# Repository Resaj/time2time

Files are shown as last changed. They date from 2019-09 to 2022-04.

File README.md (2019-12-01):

# time2time

Chronometer with partials measurement for the line-following competitions.

Characteristics:
- ESP32 module (STM microcontroller + Bluetooth + Wifi)
- Industrial distance sensor for robots pass-through detection
- Lipo 1S battery
- USB Lipo battery charge management
- I2C OLED display port
- Buzzer for robots pass-through signaling
- RGB led for chronometer status signaling
- Firmware upload via USB
- Address selection to synchronize several modules
- Expansion port for future improvements

<p align="center">
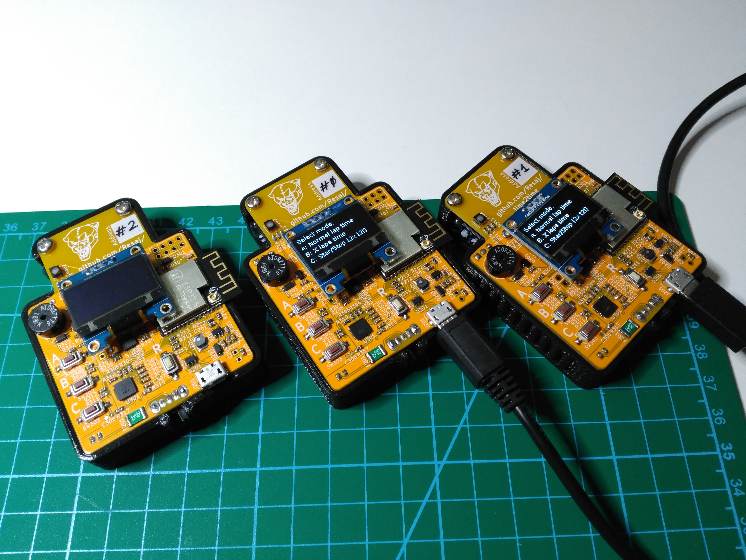
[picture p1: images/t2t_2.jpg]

</p>

This project has been motivated because of the limitations that the last chronometer had. The main purpose is to communicate the system with the PC of the competition organization and facilitate the taking and visualization of the times.

## Author

[Rubén Espino San José](https://github.com/Resaj)

## License

<p align="center">

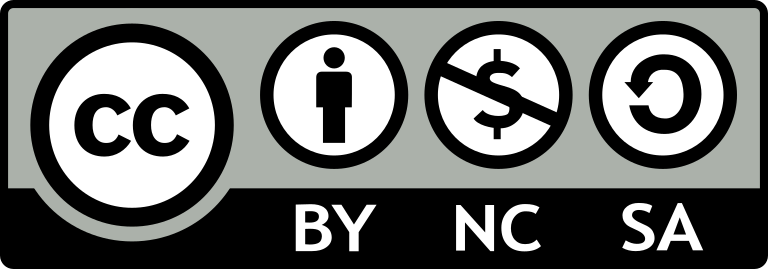
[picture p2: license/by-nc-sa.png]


</p>

_All these products are released under [Creative Commons Attribution-NonCommercial-ShareAlike 4.0 International License](http://creativecommons.org/licenses/by-nc-sa/4.0/)._

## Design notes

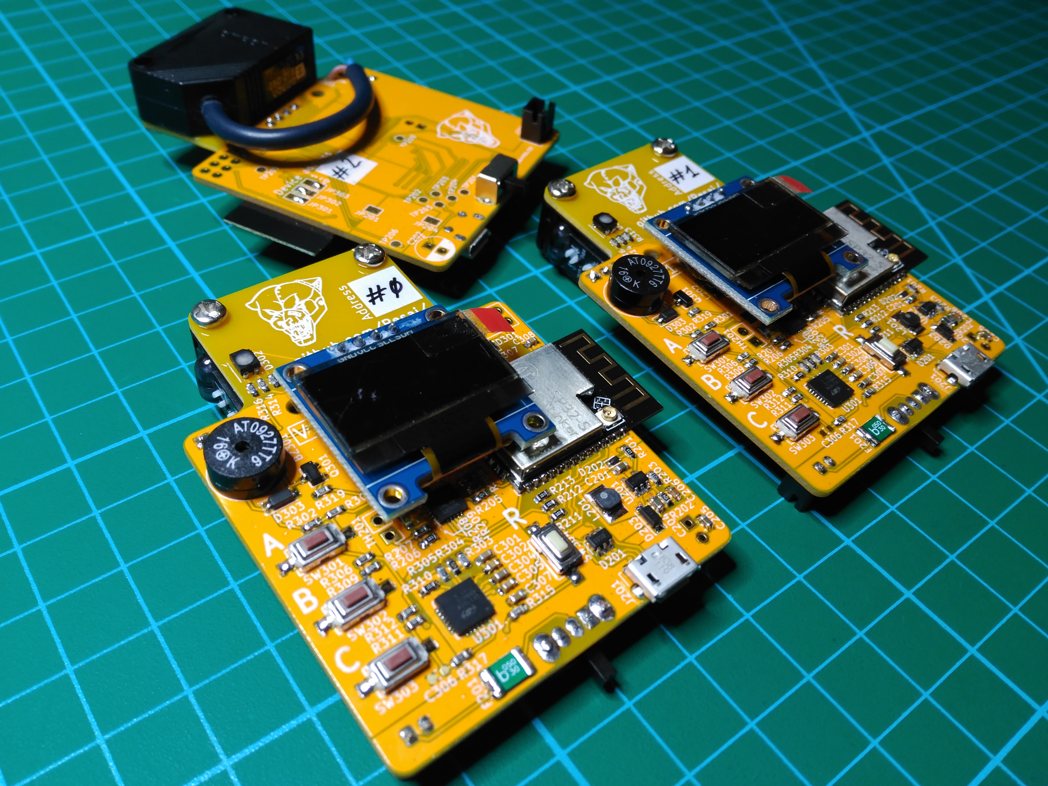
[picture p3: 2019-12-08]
images/t2t_3.jpg

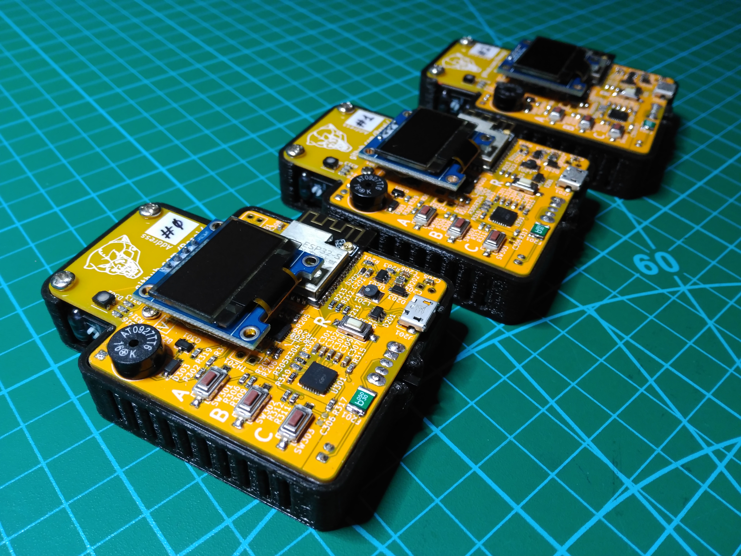
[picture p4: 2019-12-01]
images/t2t_1.jpg

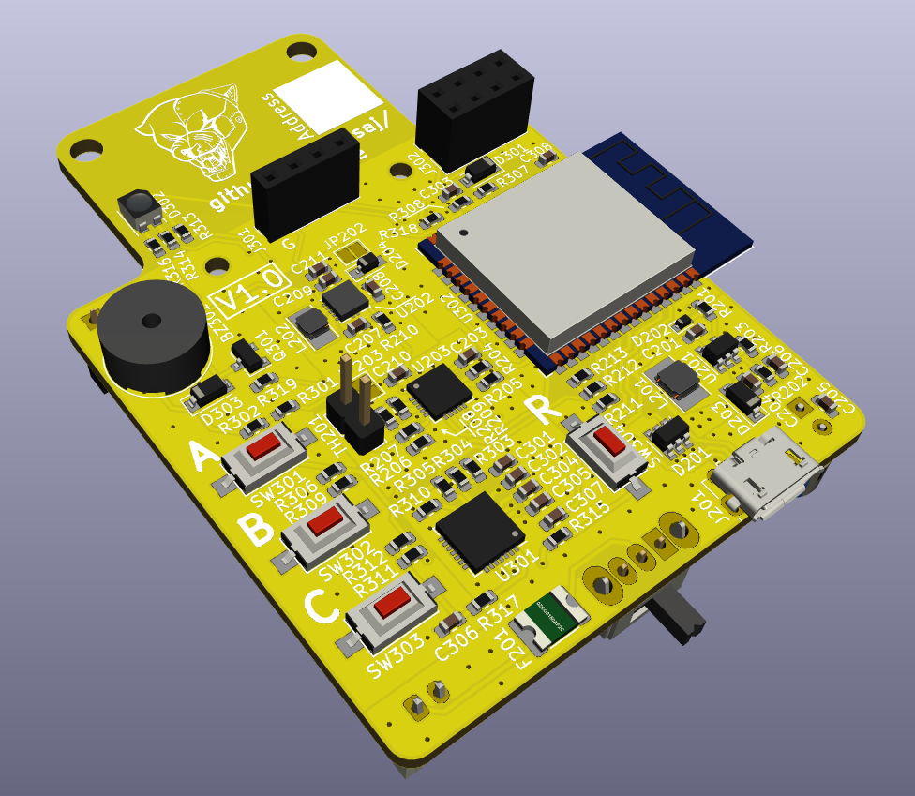
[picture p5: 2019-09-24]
images/PCB_V1_0.png

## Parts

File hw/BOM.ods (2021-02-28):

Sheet: General
Item | Quantity | Value | Link
PCB | 1
PCB components | See next sheet
Battery | 1 | Lipo 1S 2Ah 1C | Hobbyking (https://hobbyking.com/en_us/turnigy-2000mah-1s-1c-lipoly-w-2-pin-jst-ph-connector.html?___store=en_us)
Sensor | 1 | E3Z-D62 | Aliexpress (https://es.aliexpress.com/item/32865266371.html)
Display | 1 |  | Aliexpress (https://es.aliexpress.com/item/32956051129.html)
M3 screw | 2

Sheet: PCB components
Reference | Quantity | Value | Footprint | Link
BZ301, | 1 | AT-0927-TT-6-R | Buzzer_Beeper:MagneticBuzzer_PUI_AT-0927-TT-6-R | 665-AT0927TT6R (https://www.mouser.es/ProductDetail/PUI-Audio/AT-0927-TT-6-R)
C202, | 1 | 220uF | Capacitor_THT:CP_Radial_D6.3mm_P2.50mm | 140-REA221M1ABK0611P (https://www.mouser.es/ProductDetail/Lelon/REA221M1ABK-0611P?qs=sGAEpiMZZMtZ1n0r9vR22Z8b58wL7NwvkIpRinym1SQ=)
C204, | 1 | 10uF 16V | Capacitor_SMD:C_0603_1608Metric
C205, C203, C210, C207, C209, C211, C201, | 7 | 10uF | Capacitor_SMD:C_0603_1608Metric
C206, | 1 | 220pF | Capacitor_SMD:C_0603_1608Metric
C208, C303, C302, C305, C308, | 5 | 100nF | Capacitor_SMD:C_0603_1608Metric
C301, C304, | 2 | 4.7uF | Capacitor_SMD:C_0603_1608Metric
C306, | 1 | N/A | Capacitor_SMD:C_0603_1608Metric
C307, | 1 | 1uF | Capacitor_SMD:C_0603_1608Metric
D201, | 1 | ESDA6V1BC6 | Package_TO_SOT_SMD:SOT-23-6 | 511-ESDA6V1BC6 (https://www.mouser.es/ProductDetail/STMicroelectronics/ESDA6V1BC6)
D202, D304, | 2 | RB751S40T5G | Diode_SMD:D_SOD-523 | 863-RB751S40T5G (https://www.mouser.es/ProductDetail/ON-Semiconductor/RB751S40T5G)
D203, D303, | 2 | 1N4148W-7-F | Diode_SMD:D_SOD-123 | 621-1N4148W-F (https://www.mouser.es/ProductDetail/Diodes-Incorporated/1N4148W-7-F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)
D204, | 1 | MM3Z3V3ST1G | Diode_SMD:D_SOD-323_HandSoldering | 863-MM3Z3V3ST1G (https://www.mouser.es/ProductDetail/ON-Semiconductor/MM3Z3V3ST1G)
D301, | 1 | BAV19W-TP | Diode_SMD:D_SOD-123 | 833-BAV19W-TP (https://www.mouser.es/ProductDetail/Micro-Commercial-Components-MCC/BAV19W-TP)
D302, | 1 | CLVBA-FKA-CA1D181BB7D3D3 | LED_SMD:LED_Cree-PLCC4_3.2x2.8mm_CCW | 941-CLVBAFKACA1D181B (https://www.mouser.es/ProductDetail/Cree-Inc/CLVBA-FKA-CA1D181BB7D3D3)
F201, | 1 | 1A | Fuse:Fuse_1812_4532Metric | 530-0ZCG0050AF2C (https://www.mouser.es/ProductDetail/Bel-Fuse/0ZCG0050AF2C)
J201, | 1 | USB_B_Micro | Connector_USB:USB_Micro-B_Molex-105017-0001 | 538-105017-0001 (https://www.mouser.es/ProductDetail/Molex/105017-0001)
J202, | 1 | LIPO 1S | Connector_JST:JST_PH_B2B-PH-K_1x02_P2.00mm_Vertical | 571-6-440054-2 (https://www.mouser.es/ProductDetail/TE-Connectivity-AMP/6-440054-2)
J301, | 1 | Conn_display | Connector_PinSocket_2.54mm:PinSocket_1x04_P2.54mm_Vertical
J302, | 1 | Conn_expansion | Connector_PinSocket_2.54mm:PinSocket_2x04_P2.54mm_Vertical
J303, | 1 | Conn_E3Z-D62 | Connector_PinSocket_2.54mm:PinSocket_1x03_P2.54mm_Vertical
JP201, JP202, JP203, JP204, | 4 | Jumper_NC_Small | Jumper:SolderJumper-2_P1.3mm_Bridged_Pad1.0x1.5mm
JP301, JP302, JP303, | 3 | Jumper | Jumper:SolderJumper-3_P1.3mm_Open_Pad1.0x1.5mm
L201, | 1 | NRH3012T6R8MN | Inductor_SMD:L_Taiyo-Yuden_NR-30xx_HandSoldering | 963-NRH3012T6R8MN (https://www.mouser.es/ProductDetail/Taiyo-Yuden/NRH3012T6R8MN)
L202, | 1 | NRH2412T2R2MNGH | Inductor_SMD:L_Taiyo-Yuden_NR-24xx_HandSoldering | 963-NRH2412T2R2MNGH (https://www.mouser.es/ProductDetail/Taiyo-Yuden/NRH2412T2R2MNGH)
Q301, | 1 | TSM2312CX | Package_TO_SOT_SMD:SOT-23 | 821-TSM2312CXRFG (https://www.mouser.es/ProductDetail/Taiwan-Semiconductor/TSM2312CX-RFG)
R203, | 1 | 12K | Resistor_SMD:R_0603_1608Metric
R204, | 1 | 1K8 | Resistor_SMD:R_0603_1608Metric
R205, R202, R309, R302, R312, | 5 | 100K | Resistor_SMD:R_0603_1608Metric
R206, R211, R212, R213, R201, R318, R310, | 7 | 10K | Resistor_SMD:R_0603_1608Metric
R207, R313, R314, R316, R319, | 5 | 1K | Resistor_SMD:R_0603_1608Metric
R208, | 1 | 0 | Resistor_SMD:R_0603_1608Metric
R209, | 1 | N/A | Resistor_SMD:R_0603_1608Metric
R210, R306, R301, R311, R317, | 5 | 100 | Resistor_SMD:R_0603_1608Metric
R303, | 1 | 22K | Resistor_SMD:R_0603_1608Metric
R304, R307, | 2 | 47K | Resistor_SMD:R_0603_1608Metric
R305, | 1 | 4K7 | Resistor_SMD:R_0603_1608Metric
R308, | 1 | 120K | Resistor_SMD:R_0603_1608Metric
R315, | 1 | 10 | Resistor_SMD:R_0603_1608Metric
SW201, | 1 | SW_SPDT | Button_Switch_THT:SW_CuK_OS102011MA1QN1_SPDT_Angled | Aliexpress (https://es.aliexpress.com/item/32866575265.html)
SW302, SW301, SW303, SW304, | 4 | SW_Push | Button_Switch_SMD:SW_SPST_CK_RS282G05A3 | Aliexpress (https://es.aliexpress.com/item/32672806661.html)
TH201, | 1 | Thermistor_NTC | Connector_PinHeader_2.54mm:PinHeader_1x02_P2.54mm_Vertical
TP201, TP202, TP203, TP204, TP205, TP206, TP207, TP208, TP209, | 9 | TestPoint | TestPoint:TestPoint_Pad_D1.5mm
U201, | 1 | LMR62421XMF | Package_TO_SOT_SMD:SOT-23-5 | 926-LMR62421XMF/NOPB (https://www.mouser.es/ProductDetail/Texas-Instruments/LMR62421XMF-NOPB?qs=sGAEpiMZZMsbR107t9nSDXOBxw9llnCB)
U202, | 1 | TPS63001 | Package_SON:Texas_DRC0010J_ThermalVias | 595-TPS63001DRCR (https://www.mouser.es/ProductDetail/Texas-Instruments/TPS63001DRCR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)
U203, | 1 | MCP73871-2CC | Package_DFN_QFN:QFN-20-1EP_4x4mm_P0.5mm_EP2.5x2.5mm | 579-MCP73871-2CCI/ML (https://www.mouser.es/ProductDetail/Microchip-Technology/MCP73871-2CCI-ML)
U301, | 1 | CP2102N-A01-GQFN28 | Package_DFN_QFN:QFN-28-1EP_5x5mm_P0.5mm_EP3.35x3.35mm | 634-CP2102NA01GFN28R (https://www.mouser.es/ProductDetail/Silicon-Labs/CP2102N-A01-GQFN28R)
U302, | 1 | ESP32-WROOM-32 | RF_Module:ESP32-WROOM-32 | Aliexpress (https://es.aliexpress.com/item/32933123832.html?spm=a2g0s.9042311.0.0.274263c0AwxalR)

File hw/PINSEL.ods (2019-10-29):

Pin footprint | Pin ESP32 | Pin module | Name | Function / Description
25 | GPIO0 | 23 | BOOT | Boot mode input
35 | GPIO1 | 41 | UART_TX | UART Tx to USB
22 | GPIO2 | 22
34 | GPIO3 | 40 | UART_RX | UART Rx to USB
26 | GPIO4 | 24 | BUZZER_PWM | Buzzer PWM output
29 | GPIO5 | 34 | LED_R | Red led (RGB) output
20 | GPIO6 | 31
21 | GPIO7 | 32
22 | GPIO8 | 33
17 | GPIO9 | 28
18 | GPIO10 | 29
19 | GPIO11 | 30
14 | GPIO12 | 18 | SLEEP_12V | Sleep for sensor circuit, output
16 | GPIO13 | 20 | EXP1 | Expansion pin
13 | GPIO14 | 17 | LED_G | Green led (RGB) output
23 | GPIO15 | 21 | LED_B | Blue led (RGB) output
27 | GPIO16 | 25 | EXP2 | Expansion pin
28 | GPIO17 | 27 | PW_STATE3 | Bat. Manager - Power good, input
30 | GPIO18 | 35 | PW_STATE1 | Bat. Manager - STAT1, input
31 | GPIO19 | 38 | PW_STATE2 | Bat. Manager - STAT2, input
 | GPIO20
33 | GPIO21 | 42 | I2C_SDA_DISP | I2C SDA display OLED
36 | GPIO22 | 39 | I2C_SCL_DISP | I2C SCL display OLED
37 | GPIO23 | 36 | EXP3 | Expansion pin
 | GPIO24
10 | GPIO25 | 14 | EXP4 | Expansion pin
11 | GPIO26 | 15 | EXP5 | Expansion pin
12 | GPIO27 | 16 | SENSOR | Distance sensor input
 | GPIO28
 | GPIO29
 | GPIO30
 | GPIO31
8 | GPIO32 | 12 | BATT_MONITOR | Battery read by ADC
9 | GPIO33 | 13 | JP_ADD1 | Node address input
6 | GPIO34 | 10 | JP_ADD2 | Node address input
7 | GPIO35 | 11 | JP_ADD3 | Node address input
4 | GPIO36 | 5 | BUTTON1 | User button input
 | GPIO37
 | GPIO38
5 | GPIO39 | 8 | BUTTON2 | User button input

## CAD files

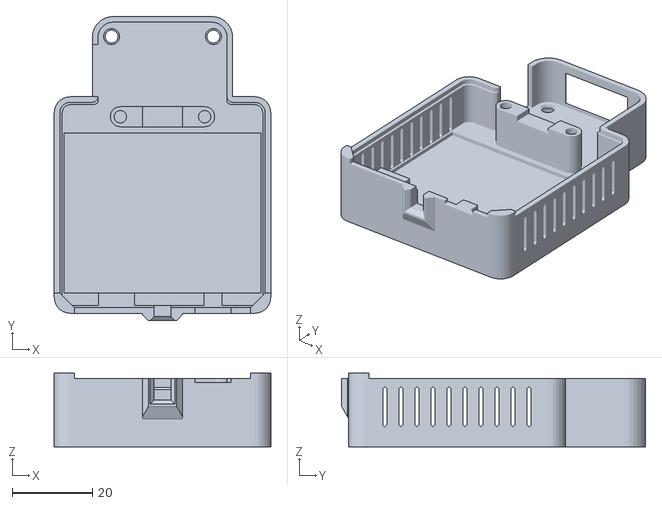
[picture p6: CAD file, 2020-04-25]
hw/FreeCAD/Casing.stl
54.0 x 75.8 x 18.4

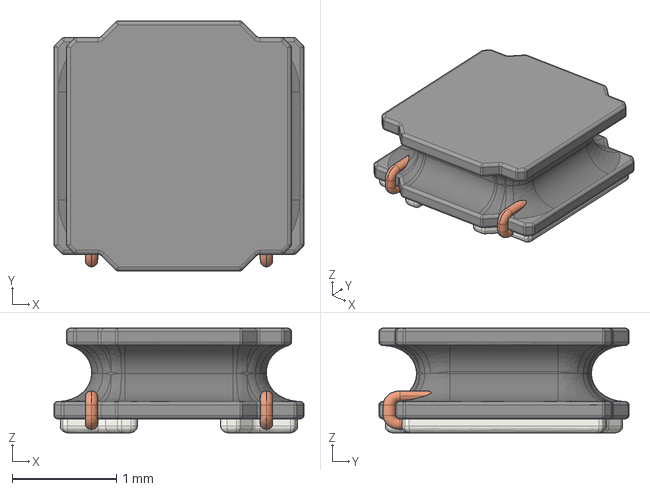
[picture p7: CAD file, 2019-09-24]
hw/Kicad/3D/L_Taiyo-Yuden_NR-2412.step
2.40 x 2.40 x 1.00 mm

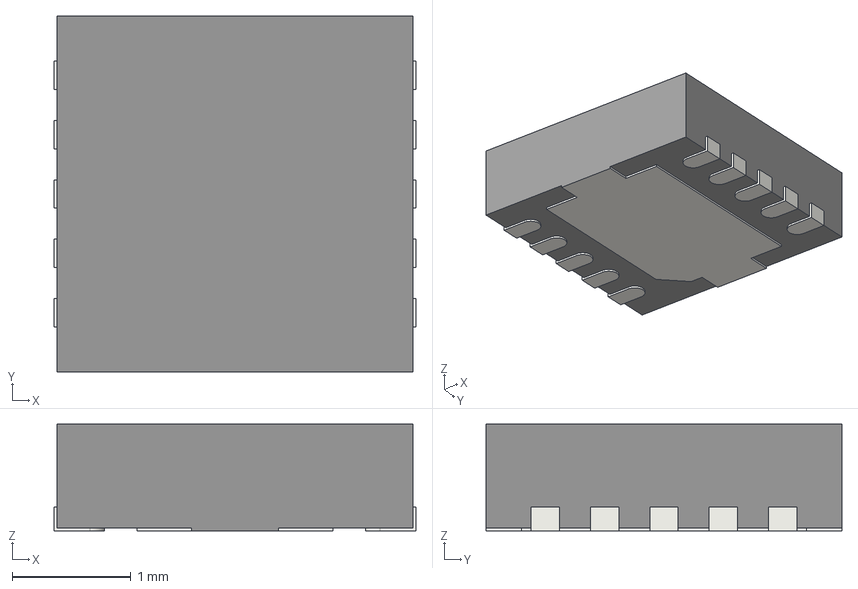
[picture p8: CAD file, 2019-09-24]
hw/Kicad/3D/Texas_DRC0010J.step
3.05 x 3.00 x 0.9 mm

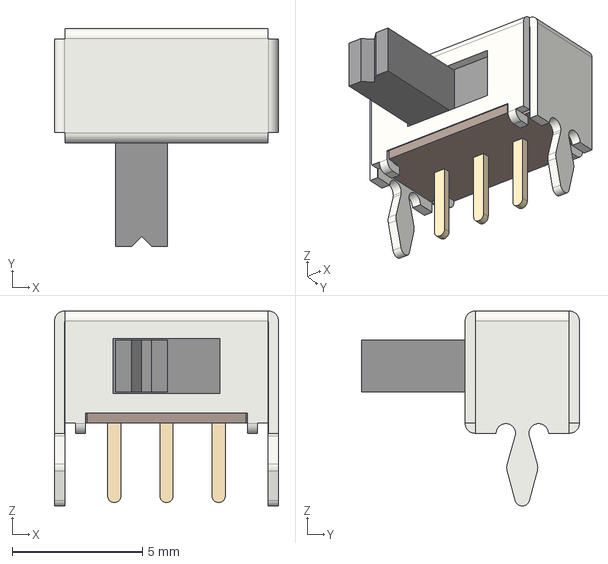
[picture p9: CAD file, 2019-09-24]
hw/Kicad/3D/SW_CuK_OS102011MA1QN1_SPDT_Angled.step
8.61 x 8.37 x 7.49 mm

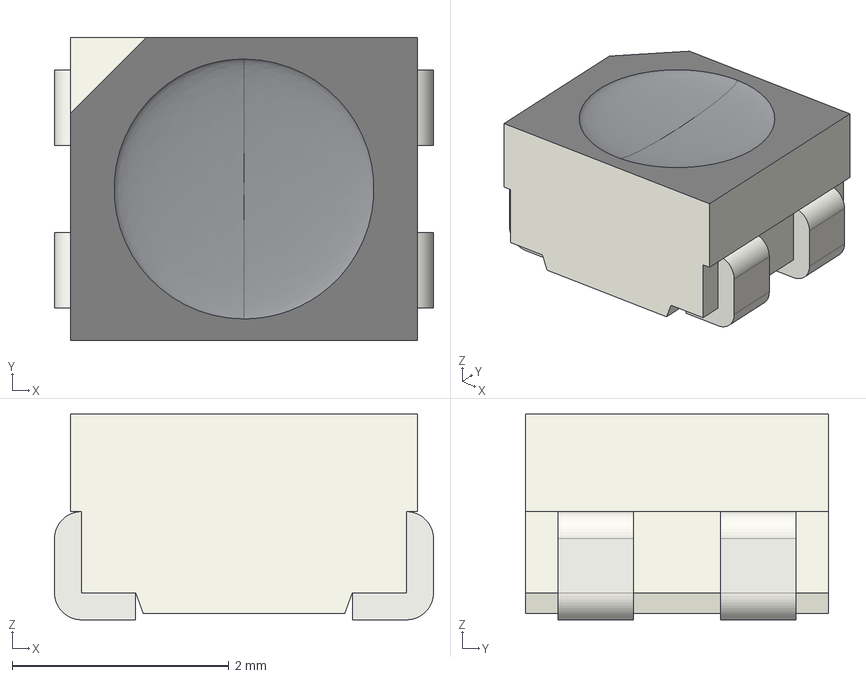
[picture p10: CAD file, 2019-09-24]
hw/Kicad/3D/LED_Cree-PLCC4_3.2x2.8mm_CCW.step
3.50 x 2.80 x 1.90 mm

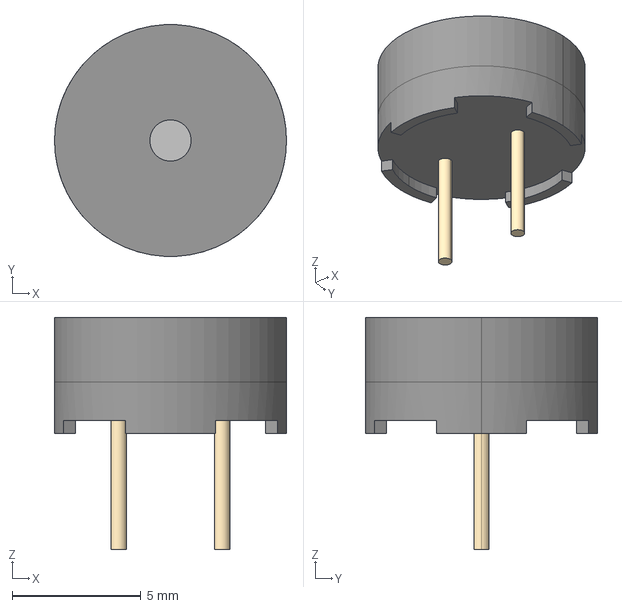
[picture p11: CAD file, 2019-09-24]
hw/Kicad/3D/MagneticBuzzer_PUI_AT-0927-TT-6-R.step
9.00 x 8.99 x 9.00 mm

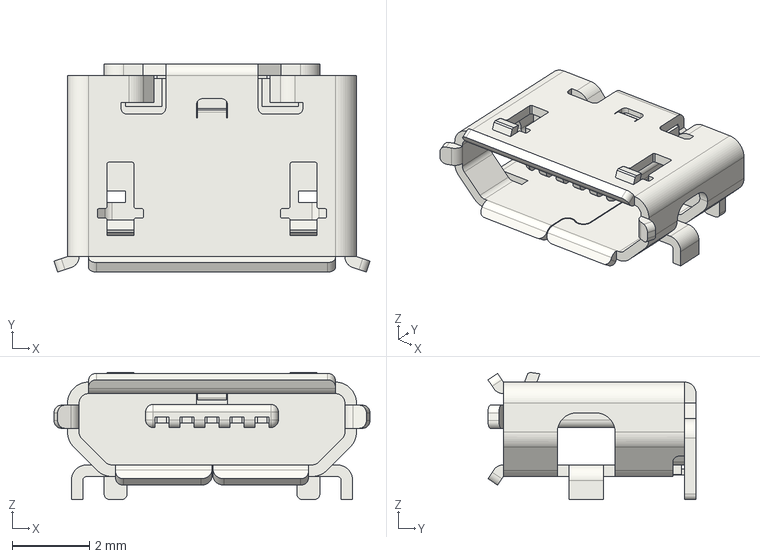
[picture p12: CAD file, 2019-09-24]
hw/Kicad/3D/USB_Micro-B_Molex-105017-0001.step
8.20 x 5.40 x 3.30 mm

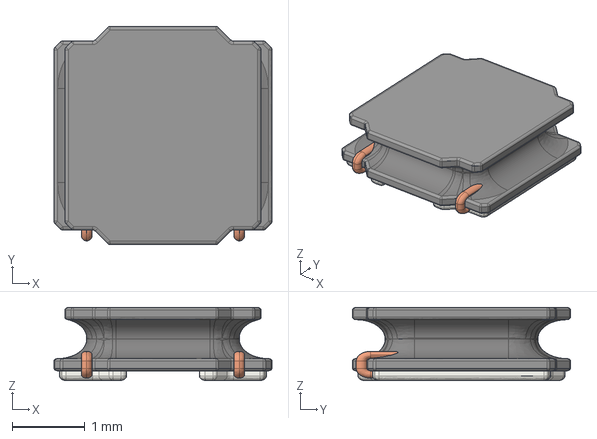
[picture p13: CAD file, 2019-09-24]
hw/Kicad/3D/L_Taiyo-Yuden_NR-3012.step
3.00 x 3.00 x 1.00 mm

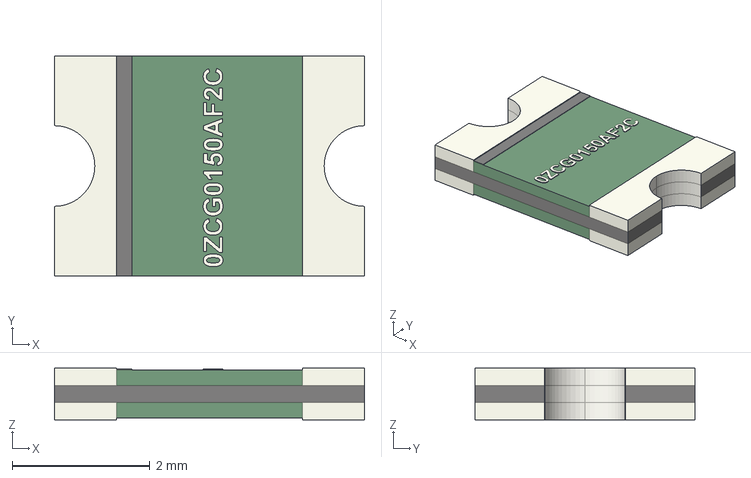
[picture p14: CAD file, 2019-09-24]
hw/Kicad/3D/Fuse_1812_4532Metric.step
4.50 x 3.20 x 0.75 mm

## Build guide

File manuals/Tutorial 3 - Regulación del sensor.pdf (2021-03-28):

Regulación del sensor de #time2time | Rubén Espino San José

# REGULACIÓN DEL SENSOR

## Regulación del sensor en distancia

El sensor de distancia de #time2time es un sensor digital de optoreflectancia, con un emisor y un receptor de luz roja. El sensor emite una luz que es reflejada por el objeto que tenga delante y detecta la luz reflejada para conocer la distancia a la que se sitúa el objeto.
Para regular el sensor hay dos potenciómetros en su parte lateral, que pueden apreciarse en la imagen izquierda.

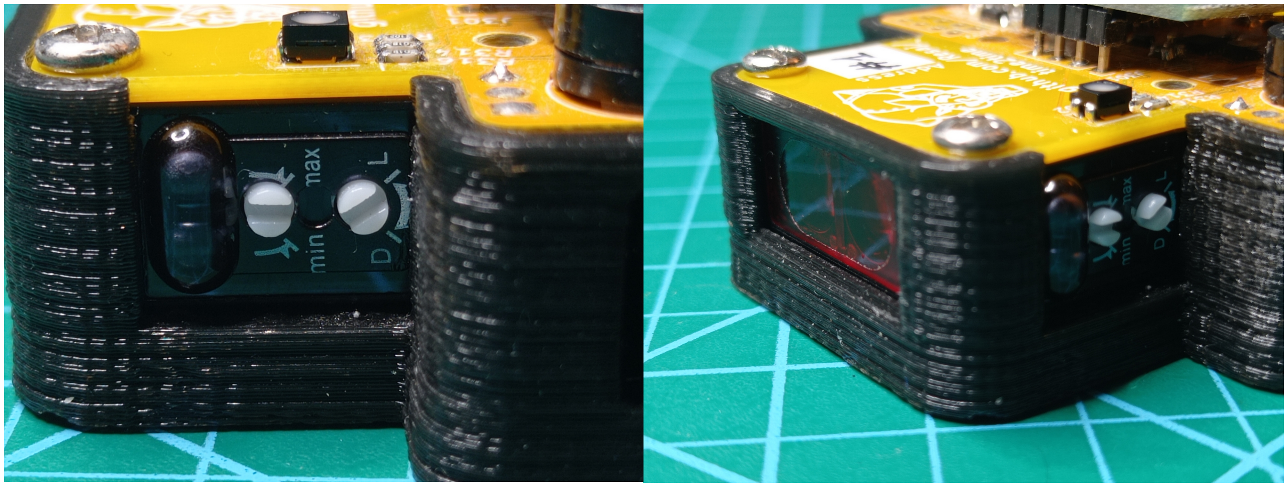
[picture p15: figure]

- Potenciómetro con la inscripción “min” y “max”: sirve para regular el umbral de distancia de detección, que puede llegar a ser de 2 metros.
- Potenciómetro con la inscripción “D” y “L”: sirve para determinar la polaridad a la salida del sensor en función de la detección. Puede ser 0 o 1.

## Problemas de reflejo del sensor con suelo blanco y regulación del sensor en altura

Uno de los detalles importantes a tener en cuenta a la hora de regular el sensor es que el emisor de luz tiene una cierta apertura. Por esta razón, si el umbral de detección es muy grande, el sensor puede llegar a detectar el suelo. Por ello es aconsejable variar la altura de #time2time para separarlo más del suelo cuanto mayor sea el umbral de detección.
Puede ocurrir que si el suelo es muy oscuro, nunca llegue a reflejar la luz por muy grande que sea el umbral de distancia especificado.
Pero también puede ocurrir que el suelo sea muy claro y sea detectado por el sensor con un umbral corto.

1

Regulación del sensor de #time2time | Rubén Espino San José

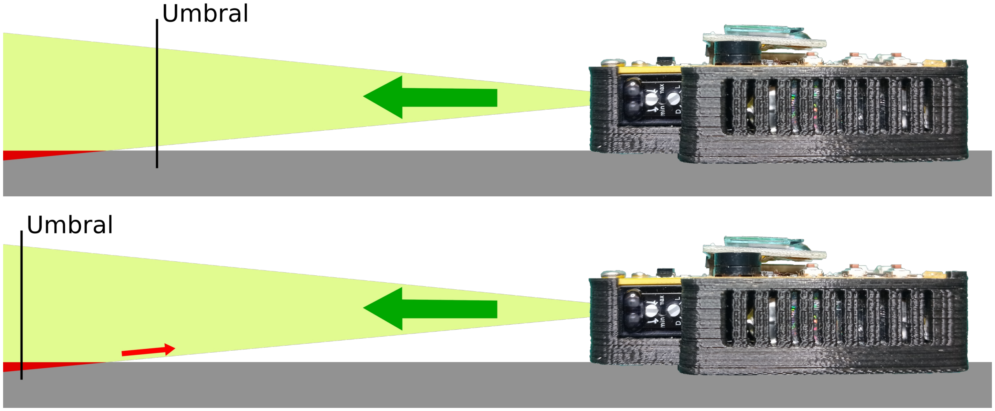
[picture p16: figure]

## Problemas de detección de objetos oscuros o cristal

Al tratarse de un sensor de luz, los colores oscuros o transparentes pueden disminuir la reflexión de la luz, por lo que es aconsejable hacer pruebas previas para ajustar el rango de detección del sensor y la altura de #time2time. Esto es especialmente importante cuando se va a realizar alguna competición de robots y cada uno de ellos está construido de una manera diferente, por lo que conviene probarlos uno a uno o estandarizar unas normas de construcción de los robots para que puedan ser detectados gracias a determinadas partes claras o reflectores que puedan reflejar la luz de vuelta al sensor.

2

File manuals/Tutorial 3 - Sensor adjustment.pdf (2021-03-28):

#time2time sensor adjustment | Rubén Espino San José

# SENSOR ADJUSTMENT

## Sensor distance adjustment

The #time2time distance sensor is a digital optoreflectance sensor, with a red light emitter and receiver. The sensor emits a light that is reflected by the object in front of it and detects the reflected light to determine the distance to the object.
To adjust the sensor there are two potentiometers on the side of the sensor. They can be seen in the left image.


- Potentiometer with the inscription “min” and “max”: it is used to adjust the detection distance threshold, which can be up to 2 meters.
- Potentiometer with the inscription “D” and “L”: it is used to determine the polarity of the sensor output depending on the detection. It can be 0 or 1.

## Sensor reflection problems with white floor and sensor height adjustment

One of the most important details to take into account when adjusting the sensor is that the light emitter has a certain aperture. Because of this reason, if the detection threshold is too high, the sensor may detect the floor. Therefore, it is advisable to vary the height of #time2time to separate it from the floor the higher the detection threshold.
It may happen that if the floor is very dark, it will never reflect the light no matter how large the specified distance threshold is.
But it can also happen that the floor is very light and is detected by the sensor with a short threshold.

1

#time2time sensor adjustment | Rubén Espino San José

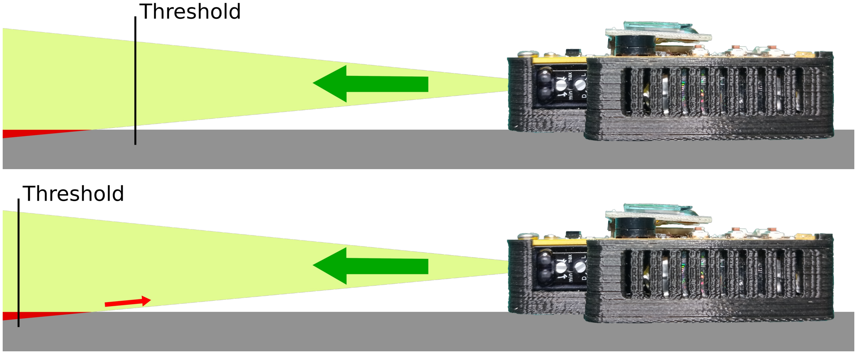
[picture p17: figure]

## Problems detecting dark objects or glass

As it is a light sensor, dark or transparent colors can decrease the light reflection, so it is advisable to do previous test to adjust the sensor detection range and the #time2time height. This is specially important when a robot competition is to be held and each robot is built differently. So it is advisable to test them one by one or to standardize the robots construction rules so that they can be detected thanks to certain light parts or reflectors that can reflect the light back to the sensor.

2

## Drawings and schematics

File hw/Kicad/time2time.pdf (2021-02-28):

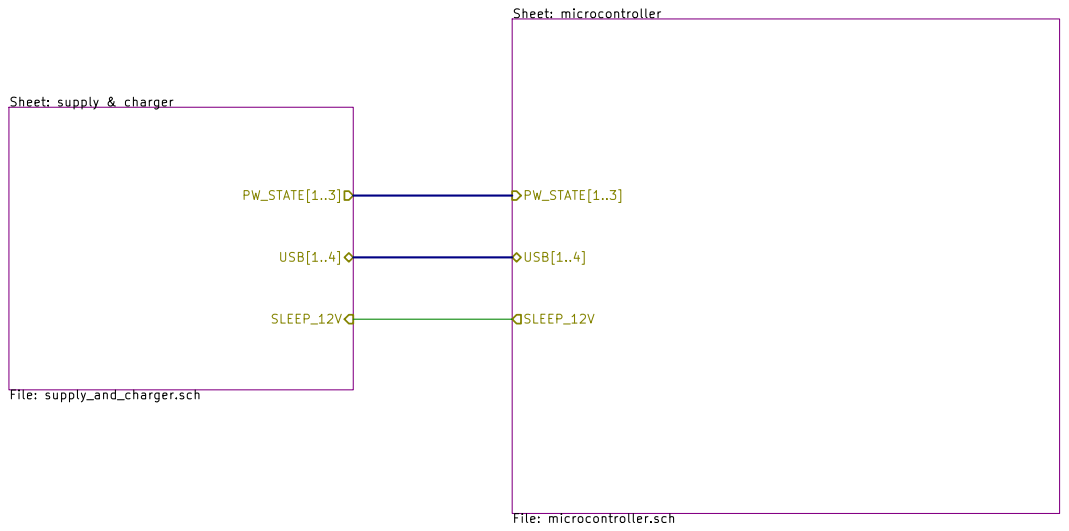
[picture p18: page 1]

Sheet: microcontroller File: microcontroller.sch USB[1..4]

Designed by Rubén Espino San José CC BY-NC-SA license

Id: 1/3 Title: time2time project File: time2time.sch Sheet: / Puma Pride Robotics Team

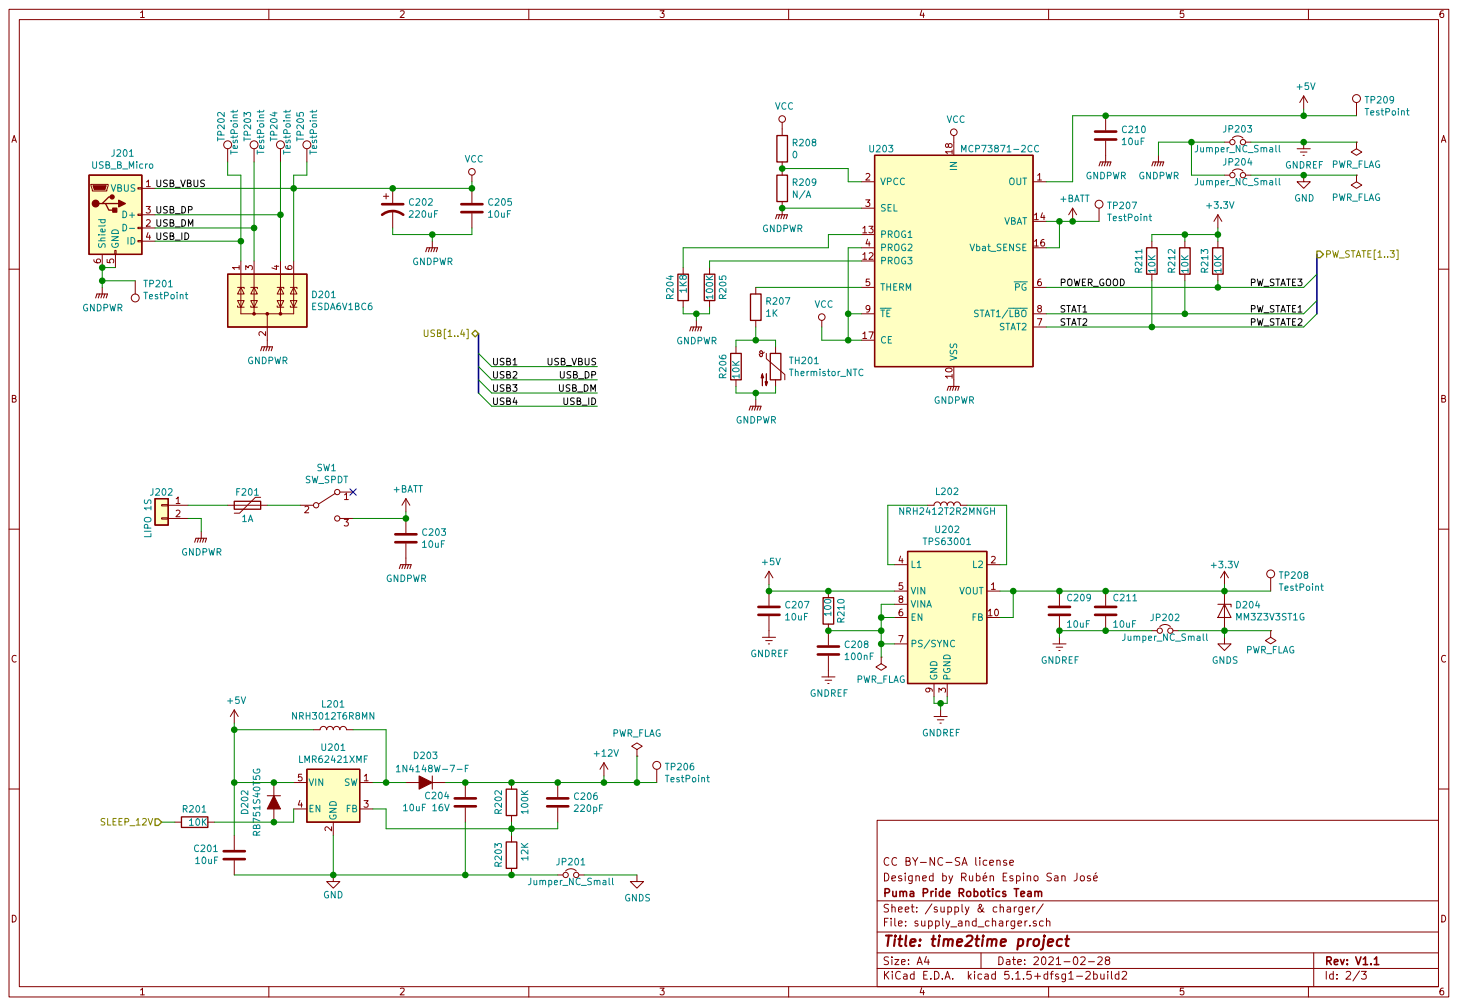
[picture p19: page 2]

6 D201 ESDA6V1BC6 TP203 TestPoint TP202 TestPoint TP204 TestPoint TP205 TestPoint TP201 TestPoint R210 100 TP206 TestPoint +12V

Designed by Rubén Espino San José CC BY-NC-SA license

Sheet: /supply & charger/ Puma Pride Robotics Team

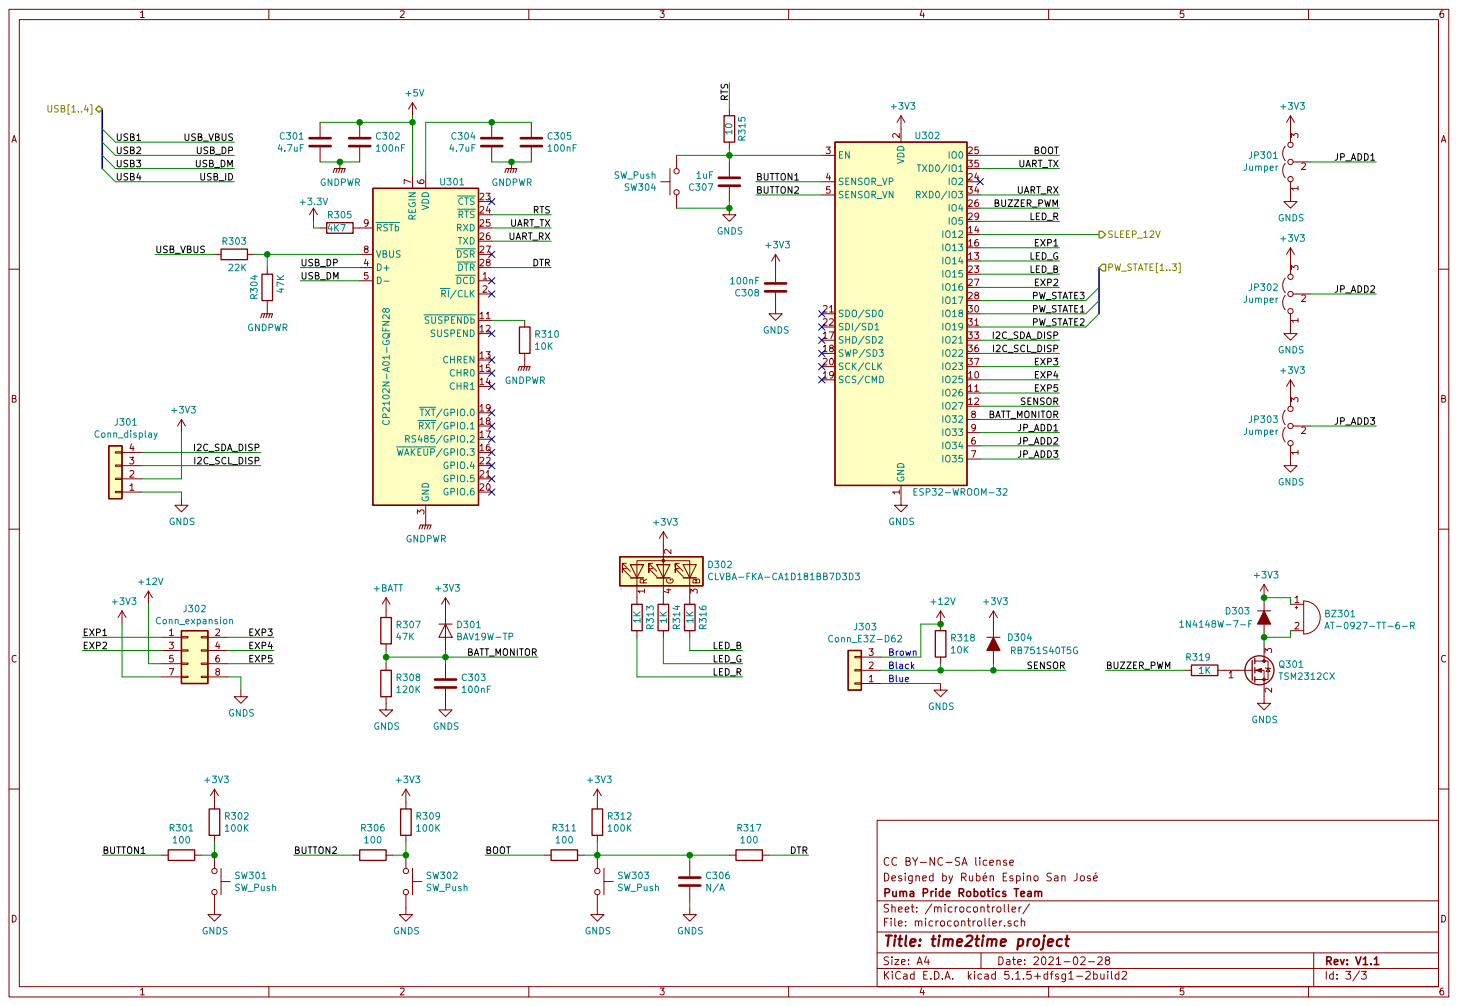
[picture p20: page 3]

Designed by Rubén Espino San José CC BY-NC-SA license

Id: 3/3 Title: time2time project File: microcontroller.sch Sheet: /microcontroller/ Puma Pride Robotics Team

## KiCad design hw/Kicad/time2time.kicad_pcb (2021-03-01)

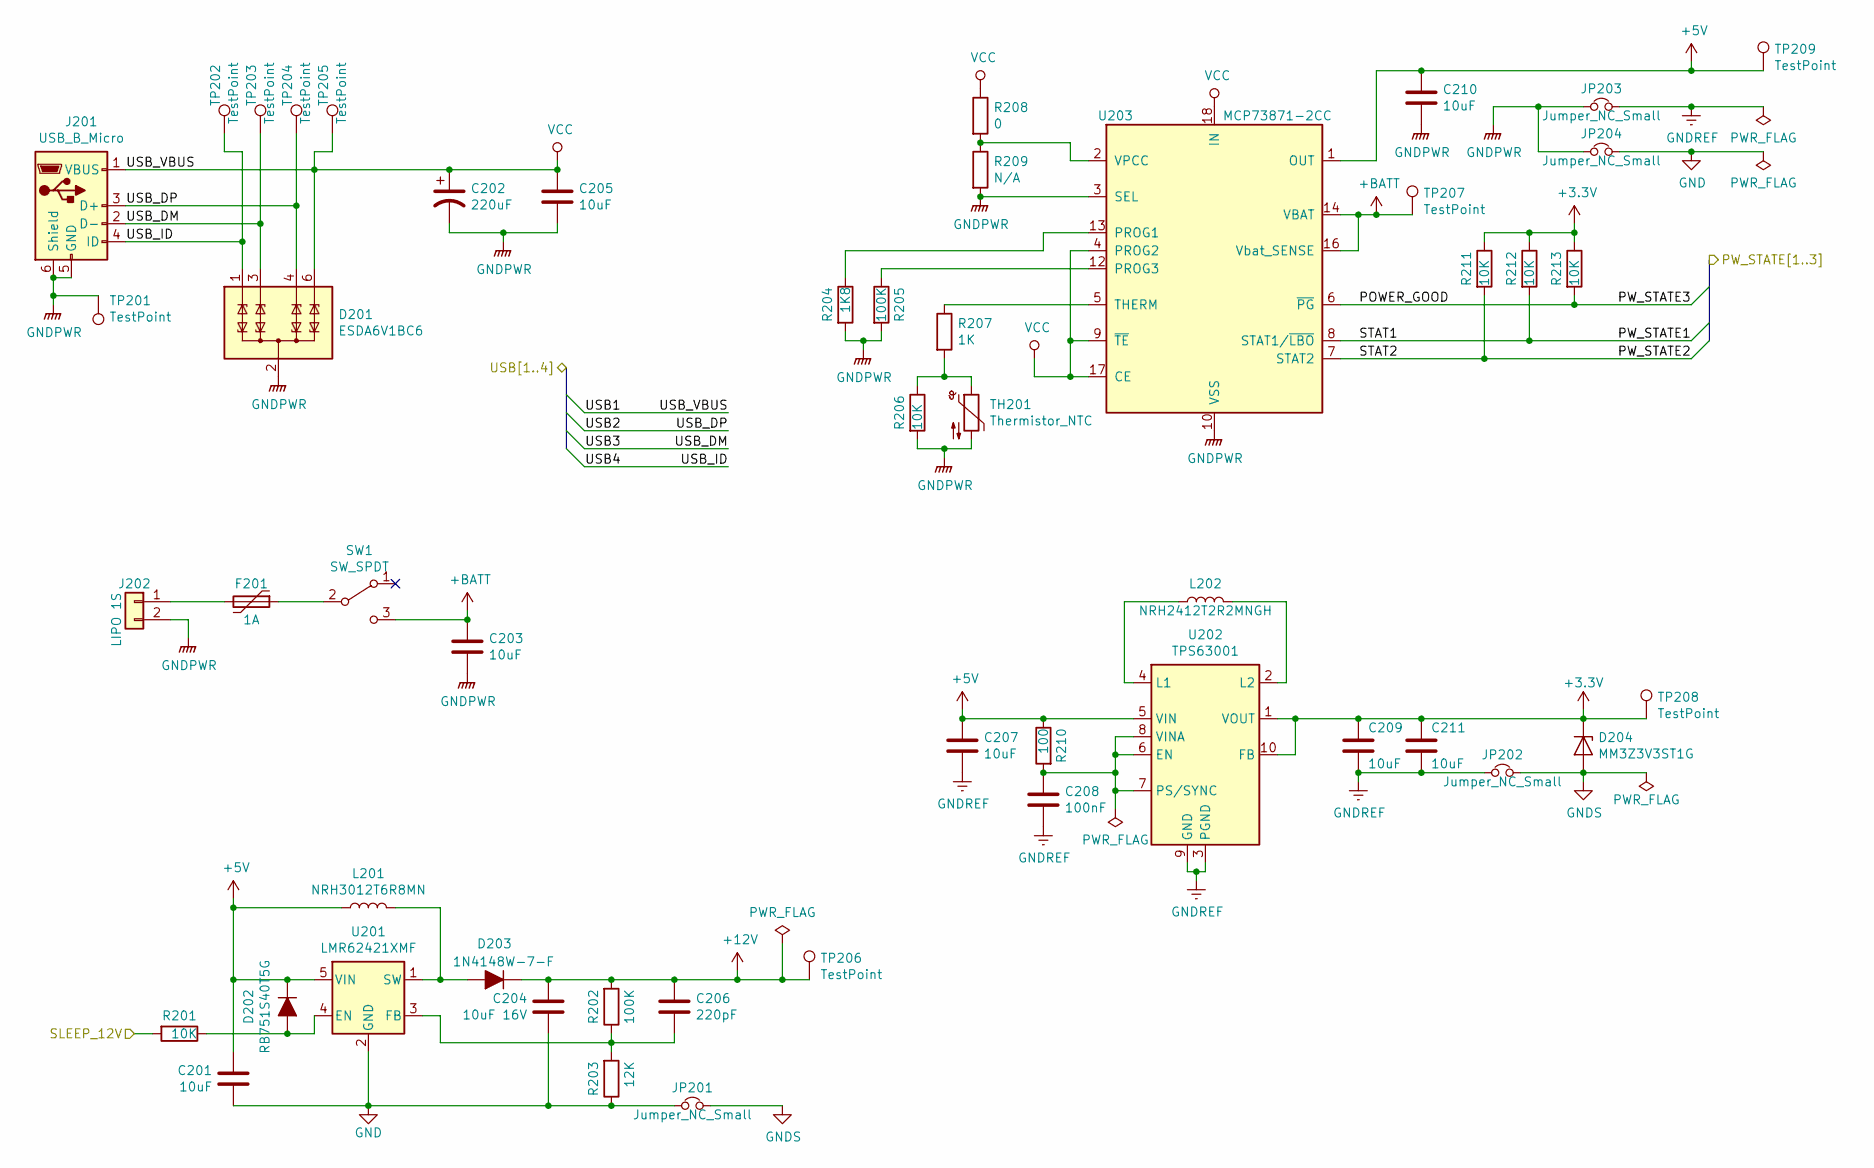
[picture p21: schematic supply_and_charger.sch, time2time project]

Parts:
C201, C203, C205, C207, C209, C210, C211: 10uF; C_0603_1608Metric
C202: 220uF; CP_Radial_D6.3mm_P2.50mm
C204: 10uF 16V; C_0603_1608Metric
C206: 220pF; C_0603_1608Metric
C208: 100nF; C_0603_1608Metric
D201: ESDA6V1BC6; SOT-23-6
D202: RB751S40T5G; D_SOD-523
D203: 1N4148W-7-F; D_SOD-123
D204: MM3Z3V3ST1G; D_SOD-323_HandSoldering
F201: 1A; Fuse_1812_4532Metric
J201: USB_B_Micro; USB_Micro-B_Molex-105017-0001
J202: LIPO 1S; JST_PH_B2B-PH-K_1x02_P2.00mm_Vertical
JP201, JP202, JP203, JP204: Jumper_NC_Small; SolderJumper-2_P1.3mm_Bridged_Pad1.0x1.5mm
L201: NRH3012T6R8MN; L_Taiyo-Yuden_NR-30xx_HandSoldering
L202: NRH2412T2R2MNGH; L_Taiyo-Yuden_NR-24xx_HandSoldering
R201, R206, R211, R212, R213: 10K; R_0603_1608Metric
R202, R205: 100K; R_0603_1608Metric
R203: 12K; R_0603_1608Metric
R204: 1K8; R_0603_1608Metric
R207: 1K; R_0603_1608Metric
R208: 0; R_0603_1608Metric
R209: N/A; R_0603_1608Metric
R210: 100; R_0603_1608Metric
SW1: SW_SPDT; SW_CuK_OS102011MA1QN1_SPDT_Angled
TH201: Thermistor_NTC; PinHeader_1x02_P2.54mm_Vertical
TP201, TP202, TP203, TP204, TP205, TP206, TP207, TP208, TP209: TestPoint; TestPoint_Pad_D1.5mm
U201: LMR62421XMF; SOT-23-5
U202: TPS63001; Texas_DRC0010J_ThermalVias
U203: MCP73871-2CC; QFN-20-1EP_4x4mm_P0.5mm_EP2.5x2.5mm

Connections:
+5V: C201.2, C207.1, C210.1, D202.1 (K), L201.1, R210.1, TP209.1, U201.5 (VIN), U202.5 (VIN), U203.1 (OUT), U203.20 (OUT); also elsewhere on the board
+12V: C204.2, C206.1, D203.1 (K), R202.2, TP206.1; also elsewhere on the board
+BATT: C203.1, SW1.3 (C), TP207.1, U203.14 (VBAT), U203.15 (VBAT), U203.16 (Vbat_SENSE); also elsewhere on the board
/microcontroller/PW_STATE1: R212.2, U203.8 (STAT1/~LBO~); also elsewhere on the board
/microcontroller/PW_STATE2: R211.2, U203.7 (STAT2); also elsewhere on the board
/microcontroller/SLEEP_12V: R201.2; also elsewhere on the board
/microcontroller/USB2: D201.4 (TVS3), J201.3 (D+), TP204.1; also elsewhere on the board
/microcontroller/USB3: D201.3 (TVS2), J201.2 (D-), TP203.1; also elsewhere on the board
/microcontroller/USB4: D201.1 (TVS1), J201.4 (ID), TP202.1
/supply & charger/POWER_GOOD: R213.2, U203.6 (~PG~); also elsewhere on the board
GND: C201.1, C204.1, JP201.1, JP204.2, R203.1, U201.2 (GND)
GNDPWR: C202.2, C203.2, C205.2, C210.2, D201.2 (COM), D201.5 (COM), J201.5 (GND), J201.6 (Shield), J202.2, JP203.1, JP204.1, R204.2, R205.2, R206.2, R209.2, TH201.2, TP201.1, U203.3 (SEL), U203.10 (VSS), U203.11 (VSS), U203.21 (VSS); also elsewhere on the board
GNDREF: C207.2, C208.2, C209.2, C211.2, JP202.1, JP203.2, U202.3 (PGND), U202.9 (GND), U202.11 (PGND)
GNDS: D204.2 (A), JP201.2, JP202.2; also elsewhere on the board
unnamed: C206.2, R202.1, R203.2, U201.3 (FB)
unnamed: C208.1, R210.2, U202.6 (EN), U202.7 (PS/SYNC), U202.8 (VINA)
unnamed: D202.2 (A), R201.1, U201.4 (EN)
unnamed: D203.2 (A), L201.2, U201.1 (SW)
unnamed: F201.1, SW1.2 (B)
unnamed: F201.2, J202.1
unnamed: L202.1, U202.4 (L1)
unnamed: L202.2, U202.2 (L2)
unnamed: R204.1, U203.13 (PROG1)
unnamed: R205.1, U203.12 (PROG3)
unnamed: R206.1, R207.2, TH201.1
unnamed: R207.1, U203.5 (THERM)
unnamed: R208.2, R209.1, U203.2 (VPCC)
VCC: C202.1, C205.1, D201.6 (TVS4), J201.1 (VBUS), R208.1, TP205.1, U203.4 (PROG2), U203.9 (~TE), U203.17 (CE), U203.18 (IN), U203.19 (IN); also elsewhere on the board

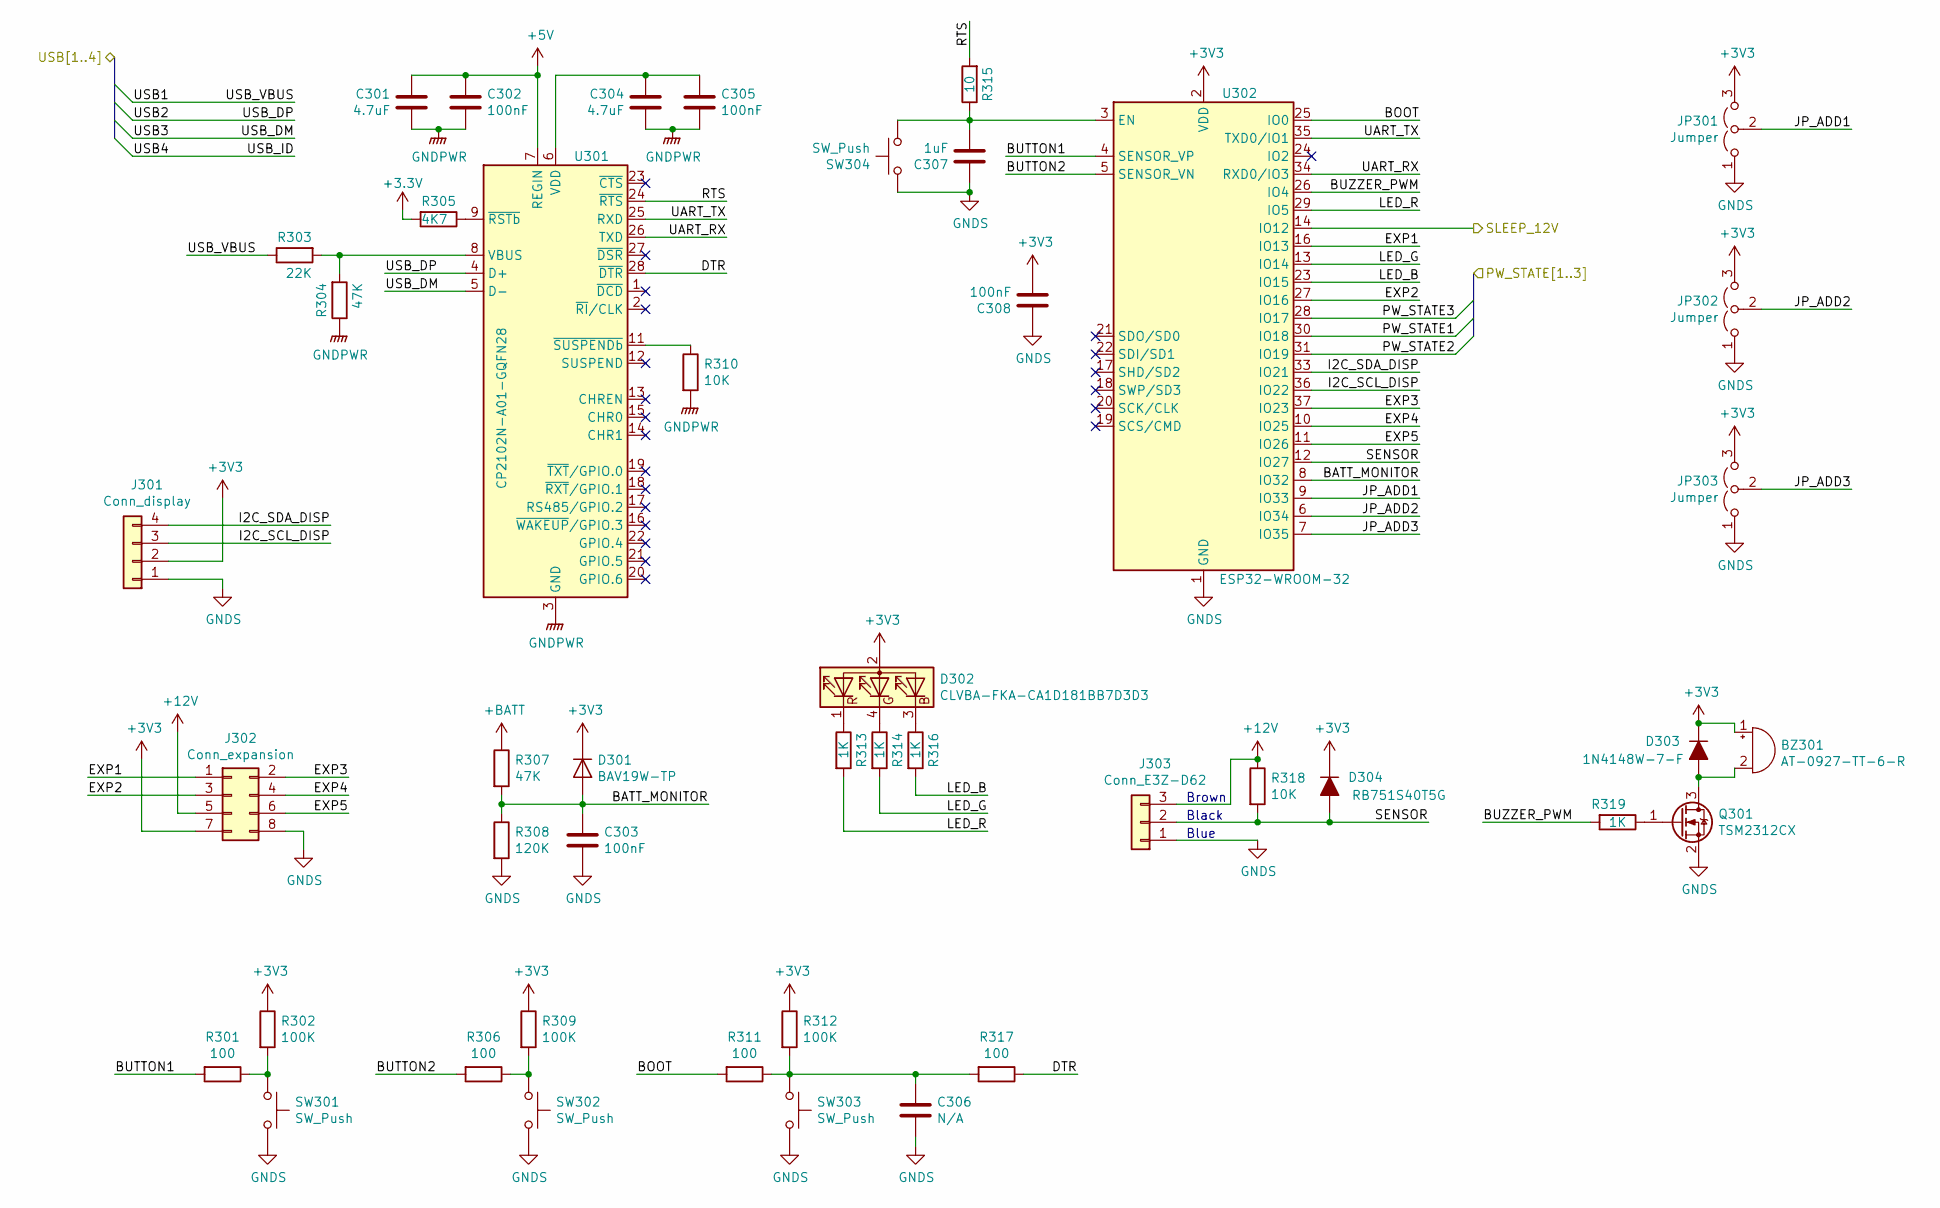
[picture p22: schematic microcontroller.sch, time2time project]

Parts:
BZ301: AT-0927-TT-6-R; MagneticBuzzer_PUI_AT-0927-TT-6-R
C301, C304: 4.7uF; C_0603_1608Metric
C302, C303, C305, C308: 100nF; C_0603_1608Metric
C306: N/A; C_0603_1608Metric
C307: 1uF; C_0603_1608Metric
D301: BAV19W-TP; D_SOD-123
D302: CLVBA-FKA-CA1D181BB7D3D3; LED_Cree-PLCC4_3.2x2.8mm_CCW
D303: 1N4148W-7-F; D_SOD-123
D304: RB751S40T5G; D_SOD-523
J301: Conn_display; PinSocket_1x04_P2.54mm_Vertical
J302: Conn_expansion; PinSocket_2x04_P2.54mm_Vertical
J303: Conn_E3Z-D62; PinSocket_1x03_P2.54mm_Vertical
JP301, JP302, JP303: Jumper; SolderJumper-3_P1.3mm_Open_Pad1.0x1.5mm
Q301: TSM2312CX; SOT-23
R301, R306, R311, R317: 100; R_0603_1608Metric
R302, R309, R312: 100K; R_0603_1608Metric
R303: 22K; R_0603_1608Metric
R304, R307: 47K; R_0603_1608Metric
R305: 4K7; R_0603_1608Metric
R308: 120K; R_0603_1608Metric
R310, R318: 10K; R_0603_1608Metric
R313, R314, R316, R319: 1K; R_0603_1608Metric
R315: 10; R_0603_1608Metric
SW301, SW302, SW303, SW304: SW_Push; SW_SPST_CK_RS282G05A3
U301: CP2102N-A01-GQFN28; QFN-28-1EP_5x5mm_P0.5mm_EP3.35x3.35mm
U302: ESP32-WROOM-32

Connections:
+5V: C301.1, C302.1, U301.7 (REGIN); also elsewhere on the board
+12V: J302.5, J303.3, R318.1; also elsewhere on the board
+BATT: R307.1; also elsewhere on the board
/microcontroller/BATT_MONITOR: C303.1, D301.2 (A), R307.2, R308.1, U302.8 (IO32)
/microcontroller/BOOT: R311.2, U302.25 (IO0)
/microcontroller/BUTTON1: R301.2, U302.4 (SENSOR_VP)
/microcontroller/BUTTON2: R306.2, U302.5 (SENSOR_VN)
/microcontroller/BUZZER_PWM: R319.2, U302.26 (IO4)
/microcontroller/DTR: R317.1, U301.28 (~DTR)
/microcontroller/EXP1: J302.1, U302.16 (IO13)
/microcontroller/EXP2: J302.3, U302.27 (IO16)
/microcontroller/EXP3: J302.2, U302.37 (IO23)
/microcontroller/EXP4: J302.4, U302.10 (IO25)
/microcontroller/EXP5: J302.6, U302.11 (IO26)
/microcontroller/I2C_SCL_DISP: J301.3, U302.36 (IO22)
/microcontroller/I2C_SDA_DISP: J301.4, U302.33 (IO21)
/microcontroller/JP_ADD1: JP301.2 (C), U302.9 (IO33)
/microcontroller/JP_ADD2: JP302.2 (C), U302.6 (IO34)
/microcontroller/JP_ADD3: JP303.2 (C), U302.7 (IO35)
/microcontroller/LED_B: R316.2, U302.23 (IO15)
/microcontroller/LED_G: R314.2, U302.13 (IO14)
/microcontroller/LED_R: R313.2, U302.29 (IO5)
/microcontroller/PW_STATE1: U302.30 (IO18); also elsewhere on the board
/microcontroller/PW_STATE2: U302.31 (IO19); also elsewhere on the board
/microcontroller/RTS: R315.2, U301.24 (~RTS)
/microcontroller/SENSOR: D304.2 (A), J303.2, R318.2, U302.12 (IO27)
/microcontroller/SLEEP_12V: U302.14 (IO12); also elsewhere on the board
/microcontroller/UART_RX: U301.26 (TXD), U302.34 (RXD0/IO3)
/microcontroller/UART_TX: U301.25 (RXD), U302.35 (TXD0/IO1)
/microcontroller/USB2: U301.4 (D+); also elsewhere on the board
/microcontroller/USB3: U301.5 (D-); also elsewhere on the board
/supply & charger/POWER_GOOD: U302.28 (IO17); also elsewhere on the board
GNDPWR: C301.2, C302.2, C304.2, C305.2, R304.1, R310.2, U301.3 (GND), U301.29 (GND); also elsewhere on the board
GNDS: C303.2, C306.2, C307.1, C308.1, J301.1, J302.8, J303.1, JP301.1 (A), JP302.1 (A), JP303.1 (A), Q301.2 (S), R308.2, SW301.2, SW302.2, SW303.2, SW304.1, U302.1 (GND), U302.15 (GND), U302.38 (GND), U302.39 (GND); also elsewhere on the board
unnamed: BZ301.2 (+), D303.2 (A), Q301.3 (D)
unnamed: C304.1, C305.1, U301.6 (VDD)
unnamed: C306.1, R311.1, R312.2, R317.2, SW303.1
unnamed: C307.2, R315.1, SW304.2, U302.3 (EN)
unnamed: D302.1 (RK), R313.1
unnamed: D302.3 (BK), R316.1
unnamed: D302.4 (GK), R314.1
unnamed: Q301.1 (G), R319.1
unnamed: R301.1, R302.2, SW301.1
unnamed: R303.2, R304.2, U301.8 (VBUS)
unnamed: R305.1, U301.9 (~RSTb)
unnamed: R306.1, R309.2, SW302.1
unnamed: R310.1, U301.11 (~SUSPENDb)
VCC: R303.1; also elsewhere on the board

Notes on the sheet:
Brown
Black
Blue

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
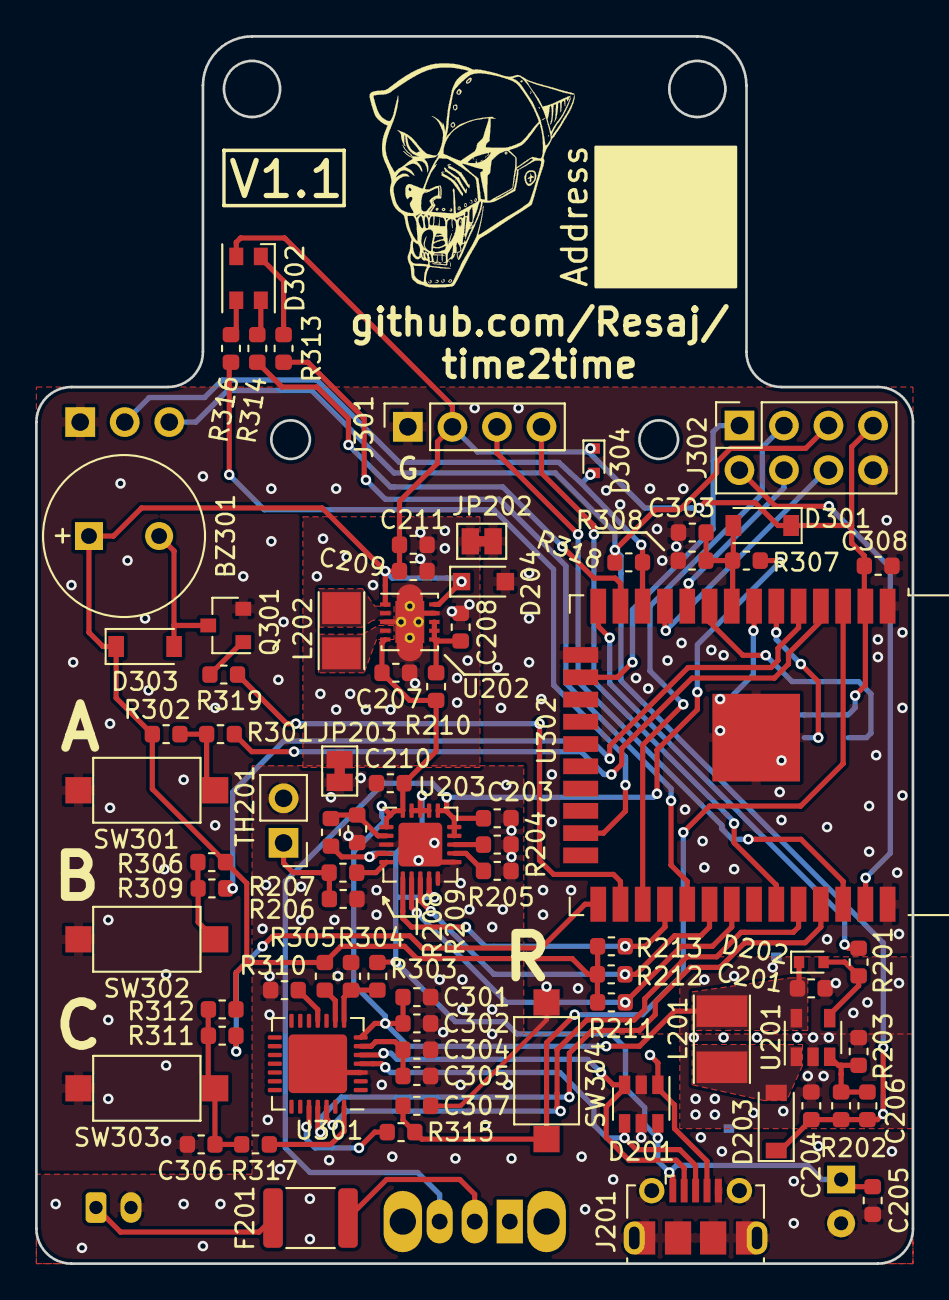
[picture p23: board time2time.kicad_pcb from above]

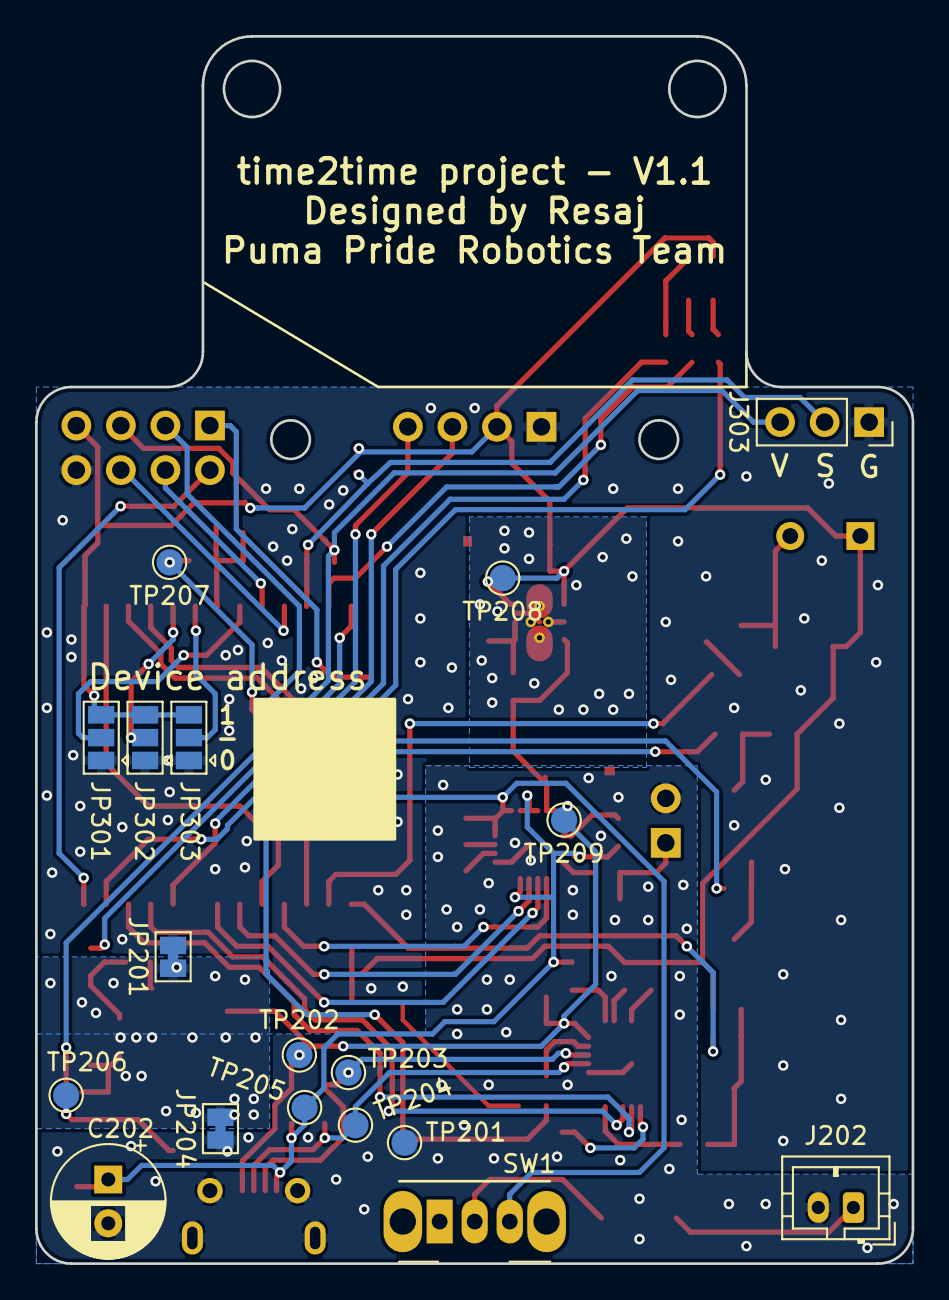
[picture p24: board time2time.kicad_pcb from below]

Board: 2 copper layers, 50.0 x 70.0 mm, 96 parts (18 on the bottom side), 65 nets.

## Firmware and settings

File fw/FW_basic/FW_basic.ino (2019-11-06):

/*****************************************************
 * Author: Rubén Espino San José
 * Puma Pride Robotics Team
 * 
 * This program is used as a chronometer to measure lap
 * times in line-following robots competitions.
 ****************************************************/

#include "PINSEL.h"
#include "SSD1306Wire.h"
#include "Crushed_Regular_65.h"

#define DISPLAY_ADDRESS 0x3C
SSD1306Wire  display(DISPLAY_ADDRESS, I2C_SDA_DISP, I2C_SCL_DISP);
#define TIMER_DISPLAY_PERIOD 1000 // us

float tShow = 0;
bool get_time = false;
bool update_time = true;
unsigned int best_time = 10000;
unsigned long time_count = 0;

float batt = 4.2;
unsigned long batt_count = 0;
#define MAX_ADC_VALUE     4095	// ADC decimal value
#define MAX_ADC_VOLT      3.3		// Volts
#define BATT_MONITOR_R1   47	  // kOhmios
#define BATT_MONITOR_R2   120	  // kOhmios
#define BATT_VOLT_ALARM   3.5	  // Volts

int buzzer_pwm_freq = 2000;
int buzzer_pwm_channel = 0;
int buzzer_pwm_resolution = 8;
bool enable_buzzer = false;
bool enable_double_beep = false;
unsigned long buzzer_count = 0;

portMUX_TYPE mux = portMUX_INITIALIZER_UNLOCKED;
bool sensor_interrupt_flag = false;

void IRAM_ATTR Sensor_isr()
{
  portENTER_CRITICAL_ISR(&mux);
  sensor_interrupt_flag = true;
  portEXIT_CRITICAL_ISR(&mux);
}

void setup() {
  pinMode(LED_R, OUTPUT);
  pinMode(LED_G, OUTPUT);
  pinMode(LED_B, OUTPUT);
  digitalWrite(LED_R, HIGH);
  digitalWrite(LED_G, HIGH);
  digitalWrite(LED_B, HIGH);

  ledcSetup(buzzer_pwm_channel,buzzer_pwm_freq,buzzer_pwm_resolution);
  ledcAttachPin(BUZZER_PWM, buzzer_pwm_channel);
  
  pinMode(SLEEP_12V, OUTPUT);
  digitalWrite(SLEEP_12V, HIGH);
  pinMode(SENSOR, INPUT);
  attachInterrupt(digitalPinToInterrupt(SENSOR), Sensor_isr, FALLING);
  
  batt = analogRead(BATT_MONITOR)*4.051/3679;
  
  display.init();
  display.flipScreenVertically();
  display.setFont(Crushed_Regular_65);
  display.setTextAlignment(TEXT_ALIGN_LEFT);

  bool get_time = true;
}

void loop() {
  if(sensor_interrupt_flag == true)
  {
    portENTER_CRITICAL(&mux);
    sensor_interrupt_flag = false;
    portEXIT_CRITICAL(&mux);
      
    if(get_time == true)
    {
      unsigned long time_lap = 0;
      
      time_lap = millis() - time_count;
      time_count = millis();
      if(time_lap < best_time)
      {
        best_time = time_lap;
        enable_double_beep = true;
      }
      enable_buzzer = true;
      ledcWrite(buzzer_pwm_channel, 125);
      buzzer_count = millis();
      drawTime(time_lap);
  
      get_time = false;
      update_time = false;
    }
  }
  
  if(millis() - batt_count > 500)
  {
    batt_count = millis();
    batt = batt*4/5 + (analogRead(BATT_MONITOR)*4.051/3679)/5;
    digitalWrite(LED_R, batt < BATT_VOLT_ALARM ? LOW : HIGH);
  }

  if(enable_buzzer == true && millis() - buzzer_count > 50)
  {
    enable_buzzer = false;
    ledcWrite(buzzer_pwm_channel, 0);

    if(enable_double_beep == true)
      buzzer_count = millis();
  }

  if(enable_double_beep == true && enable_buzzer == false && millis() - buzzer_count > 90)
  {
    enable_double_beep = false;
    enable_buzzer = true;
    ledcWrite(buzzer_pwm_channel, 125);
    buzzer_count = millis();
  }
  
  if(update_time == false && millis() - time_count >= 2000)
	  update_time = true;
  if (get_time == false && millis() - time_count >= 1000)
	  get_time = true;
  
  if(update_time == true)
    drawTime(millis() - time_count);
}

void drawTime(unsigned long TimeDisp) {
  display.clear();
  display.drawString(0, 0, String(TimeDisp/1000.0, 3));
  display.display();
}

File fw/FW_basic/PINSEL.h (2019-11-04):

#define UART_TX			  1
#define UART_RX			  3
#define BUZZER_PWM		4
#define LED_R			    5
#define LED_G			    14
#define LED_B			    15
#define SLEEP_12V		  12
#define EXP1			    13
#define EXP2			    16
#define EXP3			    23
#define EXP4			    25
#define EXP5			    26
#define POWER_GOOD		17
#define STAT1			    18
#define STAT2			    19
#define I2C_SDA_DISP  21
#define I2C_SCL_DISP	22
#define SENSOR			  27
#define BATT_MONITOR	32
#define JP_ADD1			  33
#define JP_ADD2			  34
#define JP_ADD3			  35
#define BUTTON1			  36
#define BUTTON2			  39
#define BUTTON3			  0

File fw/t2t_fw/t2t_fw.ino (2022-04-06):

/**********************************************************************
 * Project: Time2time
 * 
 * File description: This program is used as a chronometer to measure 
 * times in robotics competitions.
 * 
 * Author: Rubén Espino San José
 * Puma Pride Robotics Team
 * 
 * License: Attribution-NonCommercial-ShareAlike 4.0
 * International (CC BY-NC-SA 4.0) 
 *********************************************************************/

/**********************************************************************
 * Includes
 *********************************************************************/

#include "scheduler.h"

/**********************************************************************
 * Functions
 *********************************************************************/

void setup() {
  // Initialize tasks
  init_setup_task();

  // Configure wake up mode
  esp_sleep_enable_ext0_wakeup(GPIO_NUM_0, 0);
}

void loop() {
  scheduler_task();
}

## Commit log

2019-09-24 First commit. PCB included
    [BOM.ods, Fuse_1812_4532Metric.step, LED_Cree-PLCC4_3.2x2.8mm_CCW.step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]
2019-09-26 Pins modes specified in PINSEL
    [PINSEL.ods]
2019-10-29 V1.1 version. UART fixed and some signals renamed
    [PINSEL.ods, microcontroller.sch, supply_and_charger.sch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]
2019-10-30 Resistor value changed for ADC battery monitor
    [BOM.ods, microcontroller.sch, time2time.kicad_pcb]
2019-11-03 3D casing added
    [Casing.stl]
2019-11-05 Fixed some details of 3D casing
    [Casing.stl]
2019-11-06 Fixed sensor init
2020-04-25 Casing modified for raising the sensor and holding the PCB better
    [Casing.stl]
2020-06-07 Added buttons basic functions to the complete program. Changed names of pins.
2020-06-07 t2t_fw. Added pass sensor functionality
2020-06-13 t2t_fw. Buzzer library implemented
    [buzzer.cpp, t2t_fw.ino]
2020-06-14 t2t_fw. 12v supply enable function modified
2020-06-24 t2t_fw. Minor changes on buzzer module
    [buzzer.cpp]
2020-06-24 t2t_fw. Buttons states filtered
2020-06-25 t2t_fw. Fixed errors for peripherals initialization and buttons functionament
    [buttons.cpp, t2t_fw.ino]
2020-06-25 t2t_fw. Fixed state errors of buzzer module
    [buzzer.cpp]
2020-06-27 t2t_fw. Fixed errors of supply module
    [led_rgb.cpp, supply.cpp]
2020-06-29 t2t_fw. Scheduler added with timer interruption. Display period execution changed. Sensor interruption modified
2020-07-10 t2t_fw. Buzzer module modified. Added functionality to storage and manage buzzer tasks with a circular buffer
    [buzzer.cpp]
2020-07-13 t2t_fw. Added transfer function to convert ADC value to battery voltage
    [adc2volts.ods]
2020-08-02 t2t_fw. Format changes and led task function renamed
2020-08-02 t2t_fw. RGB led module improvements added. Square, triangle and sinusoidal waves programmed
2020-08-02 t2t_fw. Added battery charger diagnostics and showed them through the led
2020-11-01 t2t_fw. Added functions to manage the sensor active edge
2020-12-13 t2t_fw. Added ESPnow protocol documentation
    [ESPnow t2t comm protocol.ods]
2021-02-28 t2t_fw. Add schottky diode to prevent the ESP32 sensor pin from exced 3V3
    [BOM.ods, microcontroller.sch, supply_and_charger.sch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]
2021-02-28 t2t_fw. Change the minimum hole size to 0.3 mm in the PCB design
    [time2time.kicad_pcb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]
2021-03-01 hw. PCB modified to compliant with the clearance of 6mil between tracks and vias
    [time2time.drl, time2time.gbl, time2time.gbo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]
2021-03-28 manuals. Added first manuals in English and Spanish. Quick user guide and sensor adjustment
2021-08-16 t2t_fw. Update ESPnow msg procotol. Add comments to the ESPnow module functions
    [ESPnow t2t comm protocol.ods]
2021-08-16 twt_fw. Fixed some details in the communication protocol
    [ESPnow t2t comm protocol.ods]
2021-08-16 t2t_fw. Fixed the checking of the MAC address
    [espnow_comm.cpp]
2021-08-17 t2t_fw. Fix MAC address checking
    [espnow_comm.cpp]
2021-08-18 t2t_test_ESPnow. Fix updating of the sensor detection to avoid send messages constantly
    [t2t_test_ESPnow.ino]
2021-08-18 t2t_fw. Initialyze peerInfo to fix the linking between the nodes
    [espnow_comm.cpp]
2021-08-26 t2t_fw. Sleep mode to charge the battery faster. Simplify the calling of the functions of the modes
2022-01-15 t2t_fw. Enable deep sleep mode with 12V sensor disabling
2022-01-20 t2t_fw. Link messages communication done
    [ESPnow t2t comm protocol.ods]
2022-01-21 t2t_fw. Send link messages periodicaly to maintain the communication alive
    [ESPnow t2t comm protocol.ods]
2022-01-22 t2t_fw. Add functionality for the battery message. Fix and simplify the detection of the number of nodes
    [ESPnow t2t comm protocol.ods]
2022-01-23 t2t_now. Unify link and sync msg type to simplify the communication. Save ESP tx and rx times to have a time control over the communication
    [ESPnow t2t comm protocol.ods]
2022-01-23 t2t_fw. Simplify linking communication
    [ESPnow t2t comm protocol.ods]
2022-01-24 t2t_fw. Adapt the mode messages protocol to manage the requests, acceptances and rejections. Prepare mode messages reception to be processed by the state machine
    [ESPnow t2t comm protocol.ods]
2022-01-30 t2t_fw. Add some functionality for the multi-node modes. Add function declarations in all the modules
    [ESPnow t2t comm protocol.ods]
2022-02-06 t2t_mode. Change mode message management to make it easier. Extract link message management to another function
    [ESPnow t2t comm protocol.ods]
2022-02-09 t2t_fw. Fix linking and communication recovery while the nodes return from the working modes. Exit from the working mode while any of the working nodes is not linked
    [espnow_comm.cpp]
2022-02-12 t2t_fw. Fix functionality about exit from the modes when a linking error on any working node happends
    [ESPnow t2t comm protocol.ods]
2022-02-15 t2t_fw. Test tx time with an example code. Modify the behaviour of the link messages tx while working to avoid sending several
    [ESPnow t2t comm protocol.ods]
2022-03-10 t2t_fw. Fix led synchronization between nodes in a working mode
    [ESPnow t2t comm protocol.ods]
2022-04-05 t2t_fw. Finish start/stop mode. Manage sensor detections and messages for detections and times to show
    [ESPnow t2t comm protocol.ods]
2022-04-05 t2t_fw. Change stop beep to be made by the secondary node in the start/stop mode
    [ESPnow t2t comm protocol.ods]
